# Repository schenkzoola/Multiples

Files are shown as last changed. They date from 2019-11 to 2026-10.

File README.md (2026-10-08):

<picture>
  <source media="(prefers-color-scheme: dark)" srcset="docs/images/logo-light.png">
  Schenktronics
</picture>

# Passive Multiple

A 3HP Eurorack passive multiple from **Schenktronics**. It has two banks of four jacks and a latching pushbutton that links the banks into one 8-jack multiple. It needs no power.

Passive Multiple front panel

## Features

- 3HP Eurorack, 15 mm deep behind the panel (skiff-friendly), and it needs no power
- 2 × 4-jack banks, or 1 × 8 when linked
- A latching link button between the banks: in = linked, out = split
- The whole kit is through-hole, with 30 solder joints

## Documentation

| Document | For | PDF |
|---|-----|-----|
| [User Manual](docs/manual.md) | Using the module | [PDF](docs/pdf/passive-multiple-manual.pdf) |
| [Assembly Guide](docs/assembly-guide.md) | Building the kit | [PDF](docs/pdf/passive-multiple-assembly-guide.pdf) |
| [Bill of Materials](docs/BOM.md) ([CSV](docs/BOM.csv)) | Parts and sourcing | |

## Repository layout

```
hardware/
  multiple/                   Main PCB (KiCad 5.1 schematic, KiCad 10 PCB)
    Multiple.sch                 Schematic
    Multiple.kicad_pcb           PCB layout
    Multiple.step                3D model
    BOM.ods                      Original BOM spreadsheet
  panel/                      Faceplate (KiCad 10, made as an aluminium PCB)
    MultipleFaceplate.kicad_pcb  Faceplate layout
docs/                         Manual, assembly guide, BOM, images
  drawings/                     Scripts that generate the drawings
  pdf/                          PDF versions and their build settings
```

## Fabrication

| Board | Size | Layers | Thickness | Notes |
|---|---|---|---|---|
| Main PCB | 15 × 100 mm | 2 | 1.6 mm | Standard green is fine |
| Faceplate | 15 × 128.5 mm | 1 | 1.6 mm | Aluminium PCB, white solder mask, black silkscreen. Only the front copper layer is used, so FR4 works too. |

## License

This hardware design and its documentation are licensed under [CC BY-NC-SA 4.0](https://creativecommons.org/licenses/by-nc-sa/4.0/). See [LICENSE](LICENSE).

The Schenktronics name and logo are trademarks of Nathan Schenk and are not covered by the CC BY-NC-SA 4.0 license.

## Links

- Tindie: <https://www.tindie.com/products/schenktronics/passive-multiple/>
- ModularGrid: <https://modulargrid.net/e/schenktronics-multiple>
- Build video: <https://www.youtube.com/watch?v=nGc3uMlrRig>
- Website: <https://schenktronics.com>

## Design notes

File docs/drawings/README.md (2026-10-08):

# Drawings

The drawings in the docs are generated by three scripts in this repo, plus one that lives elsewhere (see "Outline drawings" below). The three here use only the Python standard library.

| Script | Makes | From |
|---|---|---|
| [`make_panel_svg.py`](make_panel_svg.py) | `panel.svg`, used in the manual, and `panel-plain.svg`, the panel without captions, used on packaging labels | The faceplate KiCad file |
| [`make_assembly_svgs.py`](make_assembly_svgs.py) | `assembly-*.svg`, used in the assembly guide | The main PCB KiCad file |
| [`make_patch_svgs.py`](make_patch_svgs.py) | `patch-*.svg`, the patch examples in the manual | The faceplate KiCad file |

## Panel drawing

The panel drawing in the [user manual](../manual.md) ([`../images/panel.svg`](../images/panel.svg)) is generated from the KiCad faceplate file, [`MultipleFaceplate.kicad_pcb`](../../hardware/panel/MultipleFaceplate.kicad_pcb).

After changing the faceplate in KiCad, run this from anywhere in the repo:

```sh
python3 docs/drawings/make_panel_svg.py
```

### What it reads

| From the KiCad file | Used for |
|---|---|
| `Edge.Cuts` lines | Panel outline |
| Mounting-hole footprints and their drill sizes | Jacks (Ø6.0), the link button (Ø6.5) and the rack screw holes |
| `F.SilkS` lines, circles and text | Printed lines, the switch symbol and the labels |
| The `SchentronicsLogo` footprint | The logo, read as its silkscreen polygons and placed at the footprint's position and rotation |

The script tells holes apart by drill size, so if you change a hole size, update `JACK` and `SWITCH` at the top of the script. The "Bank A", "Bank B" and "Link button" labels are added by the script, not read from KiCad.

The faceplate file is KiCad 10's S-expression format, read with a small generic S-expression parser in the script (not regexes), since the logo's artwork lives inside a footprint and needs that footprint's position and rotation applied to come out right.

## Assembly drawings

After changing the main PCB in KiCad, run:

```sh
python3 docs/drawings/make_assembly_svgs.py
```

| Drawing | How it's made |
|---|---|
| `assembly-1-switch.svg` | Front and back board views, drawn from the board outline, pads and front silkscreen in the PCB file |
| `assembly-2-cap.svg` | Hand-built side diagram, not from KiCad |
| `assembly-3-faceplate.svg` | Side diagram. The part positions along the board come from the PCB file, and the heights are approximate. |
| `assembly-4-jacks.svg` | Back board view, drawn from the PCB file |

The side views assume the faceplate sits 27 mm further along than the PCB, matching the two KiCad files. If you move the jacks on either board, update `offset` in `fig_faceplate`.

## Patch examples

The patch drawings reuse the panel drawing and add module boxes and cables. Each example is a short function in the script, for example:

```python
def pitch(data):
    p = Patch(data)
    p.source("A1", "Sequencer", "pitch CV out")
    p.dest("A2", "VCO 1", "V/oct in")
    ...
```

Jacks are named by bank and position from the top: `A1`–`A4` and `B1`–`B4`. Sources go on the left, destinations on the right. Pass `color=BLUE` to draw a second signal. To add an example, write a new function, add it to the list in `main()`, and run:

```sh
python3 docs/drawings/make_patch_svgs.py
```

## Outline drawings

`outline-front.svg`, `outline-side.svg`, one `outline-iso-{top,bottom}-{left,right}.svg` per corner, and `outline-bare-parts.svg` (the panel and bare PCB side by side, for the assembly guide's "before you start" shot) are real projections straight from [`ST01_Multiple.step`](../../hardware/ST01_Multiple.step) in `hardware/` — not diagrams. They replace the old product photos in the README, manual and assembly guide. All four isometric corners are generated every run so there's always a fresh set to pick a hero shot from; `outline-iso-top-left.svg` is the one currently used.

**The generator for these doesn't live in this repo.** Unlike the three scripts above, it needs no product-specific logic — point it at any product's STEP files and it works unchanged — so it's kept as one shared tool in the private `schenktronics-business` repo (`claude/skills/schenktronics-product-docs/assets/drawings/make_outline_svg.py`) rather than forked into every product. Regenerate from this repo's root:

```sh
pip install cadquery  # no FreeCAD or other CAD tooling needed
python3 ~/Products/schenktronics-business/claude/skills/schenktronics-product-docs/assets/drawings/make_outline_svg.py \
  --assembly hardware/ST01_Multiple.step \
  --panel hardware/panel/MultipleFaceplate.step \
  --board hardware/multiple/Multiple.step \
  --out docs/images \
  --product "Passive Multiple"
```

(or add a view name at the end, e.g. `... outline-front.svg`, to regenerate just that one)

**This is slow, and not predictably so, especially the front view — read the module docstring in that script before touching it.** Short version: a straight-on view down an axis where many cylindrical parts line up end-on (every jack here, viewed from the front) is a degenerate case for exact-BRep HLR, both slow (the orthographic version of this view took **24 minutes**, against about a **minute each** for the side and isometric views of the same assembly) and prone to rendering a different jack inconsistently on every attempt. The fix that worked — a perspective projection with its apex centered on the model, not tilting the orthographic direction — is explained in full in the script itself, along with everything else worth knowing before changing a view (the explicit HLR axis, scientific-notation coordinate parsing, per-view subprocess isolation, the simplify/crop pass). That script is the one copy serving every product, so fixes and lessons belong there, not duplicated into each product repo's own docs.

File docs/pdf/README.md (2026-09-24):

# PDFs

Printable versions of the docs:

- [User Manual (PDF)](passive-multiple-manual.pdf)
- [Assembly Guide (PDF)](passive-multiple-assembly-guide.pdf)

These are built from [`../manual.md`](../manual.md) and [`../assembly-guide.md`](../assembly-guide.md). **Don't edit the PDFs by hand.** Edit the Markdown instead.

The build tool lives in [schenktronics-docs-tools](https://github.com/schenkzoola/schenktronics-docs-tools), so this repo only holds its settings, in [`config.json`](config.json): the product name, PCB version and which documents to build.

## Automatic builds

The [Build PDFs workflow](../../.github/workflows/pdf.yml) rebuilds the PDFs whenever the docs, their images or `config.json` change on `master`, and commits the new PDFs back. After you push a docs change, wait a minute and then `git pull` to get the rebuilt PDFs.

After an update to schenktronics-docs-tools, run the workflow by hand from the repo's **Actions** tab to rebuild with the new version.

## Previewing locally

See [Previewing locally](https://github.com/schenkzoola/schenktronics-docs-tools#previewing-locally) in the tools repo. In short:

```sh
node ~/Products/schenktronics-docs-tools/pdf/build.mjs docs/pdf/config.json
```

Don't commit the PDFs this produces. Let the workflow build the committed copies.

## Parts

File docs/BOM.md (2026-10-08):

# Bill of Materials — Passive Multiple v1.0

A machine-readable copy is in [BOM.csv](BOM.csv). The original spreadsheet is [hardware/multiple/BOM.ods](../hardware/multiple/BOM.ods).

| Qty | Reference | Part | Manufacturer / Part No. | Notes |
|----:|---|---|---|---|
| 8 | J1–J8 | 3.5 mm mono switched jack, vertical PCB mount, with nut | QingPu WQP-PJ398SM or WQP518MA, or equivalent. Either one works. | [Datasheet / product page](http://www.qingpu-electronics.com/en/products/WQP-PJ398SM-362.html). The switched (normalling) lug is not used. |
| 1 | SW1 | Pushbutton switch, DPDT, latching (push on, push off), PCB mount. It fits either way round. | APEM MHPS2285, or equivalent | [Digi-Key 679-4053-ND](https://www.digikey.com/product-detail/en/apem-inc/MHPS2285/679-4053-ND/1795385). Rated 0.1 A at 30 VDC. An equivalent must be a latching DPDT switch with the same 2 × 3 pin layout, and a plunger that fits the button cap. |
| 1 | — | Button cap, cylindrical, red | Tayda A-5390 (red, 6 × 5 mm) | [Tayda listing](https://www.taydaelectronics.com/push-button-switch-caps-red-color-6-x-5-mm-5390.html). Any cap that fits the MHPS2285 plunger and passes through the 6.5 mm panel hole will work. |
| 1 | — | Main PCB, 15 × 100 mm, 2-layer, 1.6 mm FR4 | Schenktronics | — |
| 1 | — | Faceplate, 3HP (15 × 128.5 mm), 1.6 mm aluminium PCB | Schenktronics | Single-sided, so it can also be made in FR4. |

## Not included

| Qty | Part | Notes |
|----:|---|---|
| 2 | M3 rack screws | Supplied with most Eurorack cases. |

No power cable is needed. The module is passive.

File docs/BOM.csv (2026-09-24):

Qty | Reference | Description | Manufacturer | Part Number | Link
8 | J1-J8 | 3.5mm mono switched jack, vertical, with nut | QingPu | WQP-PJ398SM or WQP518MA | http://www.qingpu-electronics.com/en/products/WQP-PJ398SM-362.html
1 | SW1 | Pushbutton switch, DPDT, latching (or equivalent with same pinout and plunger) | APEM | MHPS2285 | https://www.digikey.com/product-detail/en/apem-inc/MHPS2285/679-4053-ND/1795385
1 |  | Button cap, cylindrical, red, 6x5mm, fits MHPS2285 plunger | Tayda | A-5390 | https://www.taydaelectronics.com/push-button-switch-caps-red-color-6-x-5-mm-5390.html
1 |  | Main PCB, 15x100mm, 2-layer, 1.6mm | Schenktronics | Passive Multiple v1.0
1 |  | Faceplate, 3HP, 1.6mm aluminium PCB | Schenktronics | Passive Multiple Faceplate

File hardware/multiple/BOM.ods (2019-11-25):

Qty | Part No | Manufacturer | Description | Link
8 | WQP-WQP518MA | QuingPu | 3.5mm Jack with nut | http://www.qingpu-electronics.com/en/products/WQP-PJ398SM-362.html
1 | MHPS2285 | APEM | Switch Push DPDT | https://www.digikey.com/product-detail/en/apem-inc/MHPS2285/679-4053-ND/1795385
1 |  |  | Button Cap | https://www.aliexpress.com/item/32375524187.html
1 | PCB | Schenktronics
1 | Faceplate | Schenktronics

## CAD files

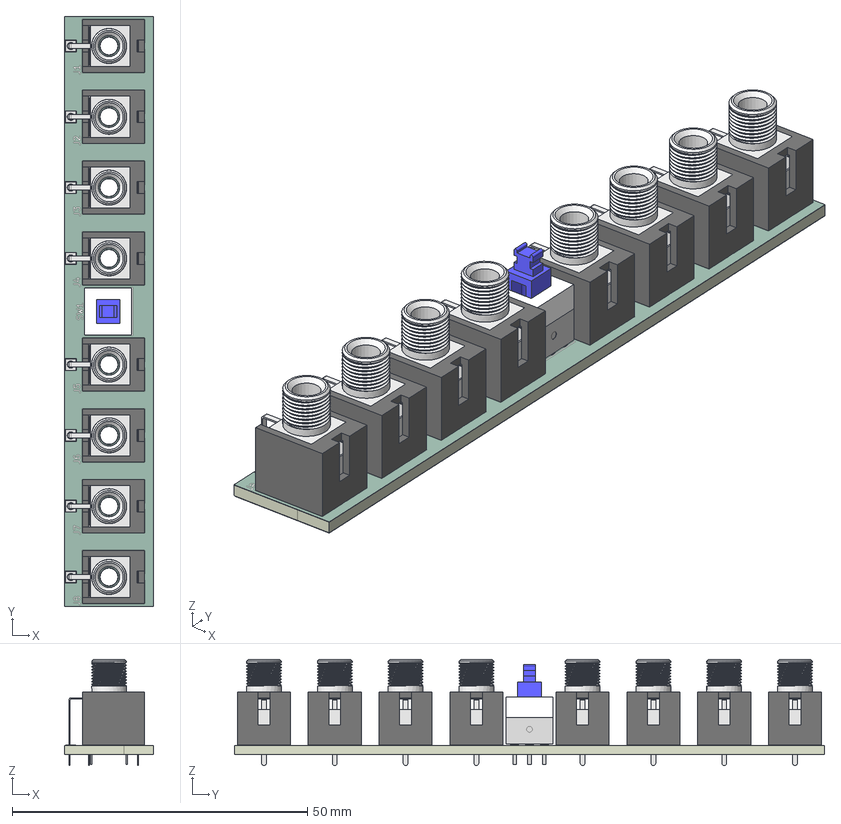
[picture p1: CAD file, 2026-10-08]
hardware/multiple/Multiple.step
15.0 x 100.0 x 18.0 mm
Thonkiconn - PJ398SM v10 x 8
TERMINALS
HOUSEING
actuator
SPRING
Multiple_copper
Multiple_pad
Multiple_silkscreen x 2
Multiple_soldermask x 2
Multiple_PCB

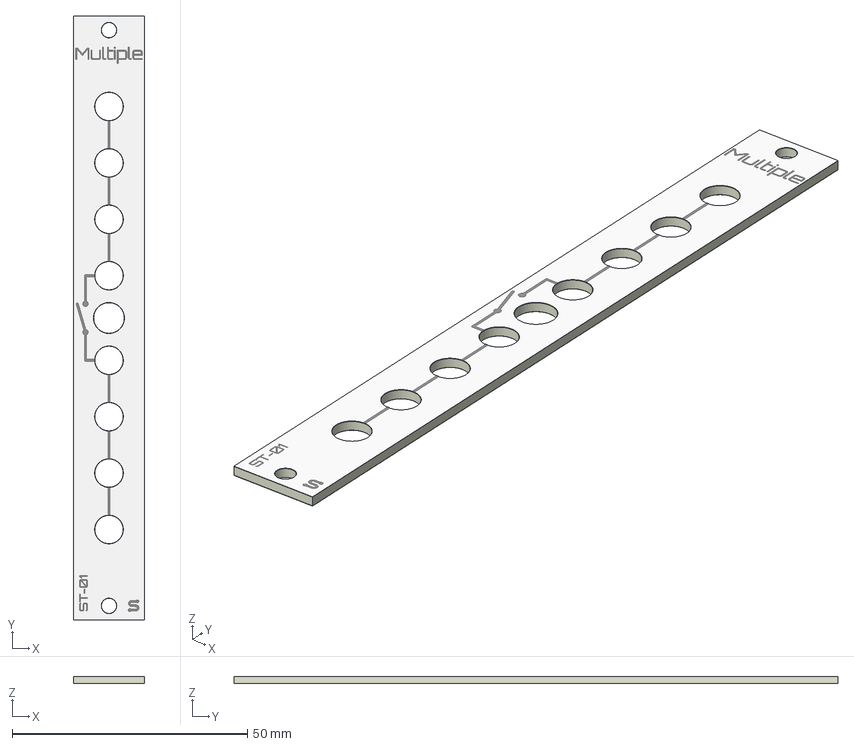
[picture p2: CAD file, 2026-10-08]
hardware/panel/MultipleFaceplate.step
15.0 x 128.5 x 1.64 mm
MultipleFaceplate-unsaved-export-87vEoI_copper
MultipleFaceplate-unsaved-export-87vEoI_silkscreen
MultipleFaceplate-unsaved-export-87vEoI_soldermask x 2
MultipleFaceplate-unsaved-export-87vEoI_PCB

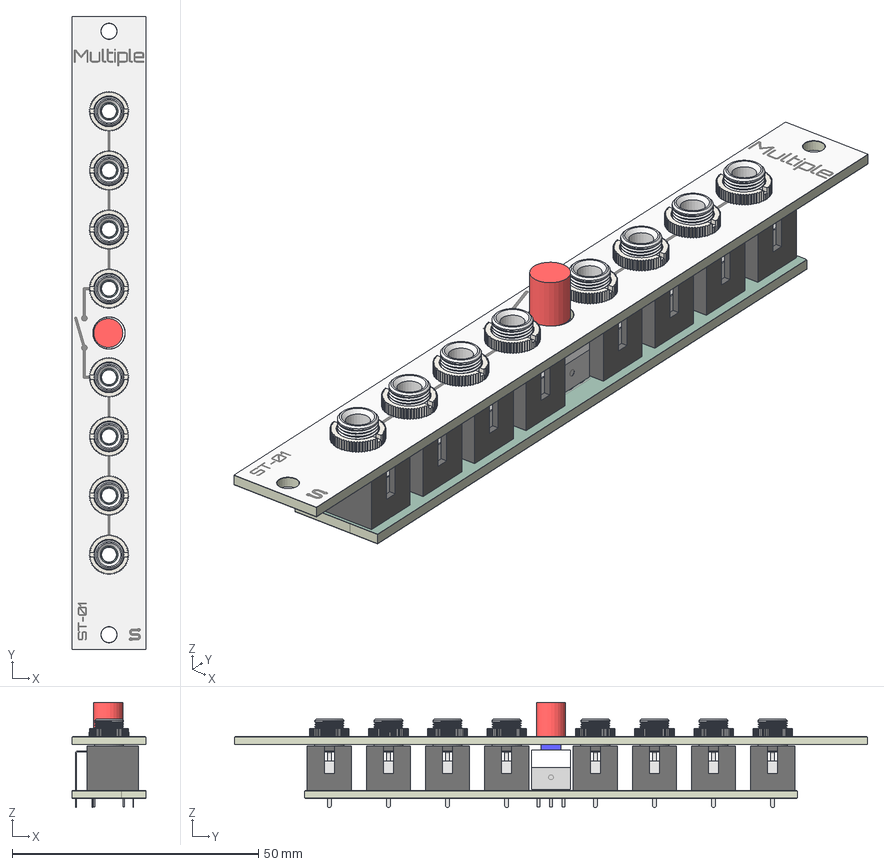
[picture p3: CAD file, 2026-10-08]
hardware/ST01_Multiple.step
15.0 x 128.5 x 21.3 mm
Thonkiconn - PJ398SM v10 x 8
TERMINALS
HOUSEING
actuator
SPRING
Multiple_copper
Multiple_pad
Multiple_silkscreen
Multiple_silkscreen_1
Multiple_soldermask
Multiple_soldermask_1
Multiple_PCB
MultipleFaceplate-unsaved-export-87vEoI_copper
MultipleFaceplate-unsaved-export-87vEoI_silkscreen
MultipleFaceplate-unsaved-export-87vEoI_soldermask
MultipleFaceplate-unsaved-export-87vEoI_soldermask_1
MultipleFaceplate-unsaved-export-87vEoI_PCB
SwitchButton

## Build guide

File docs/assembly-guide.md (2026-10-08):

# Passive Multiple — Assembly Guide

Building this kit takes about 20–30 minutes and needs 30 solder joints. It is a good first Eurorack kit.

**Prefer to watch?** There's a video of the whole build: [Watch me assemble a switched passive multiples module!](https://www.youtube.com/watch?v=nGc3uMlrRig)

The faceplate and the bare PCB, before assembly

## What you need

### Kit contents

Check your kit against this list before you start (full details in the [BOM](BOM.md)):

- [ ] 1 × main PCB
- [ ] 1 × faceplate
- [ ] 8 × 3.5 mm jacks with nuts
- [ ] 1 × latching pushbutton switch
- [ ] 1 × button cap

### Tools

- Soldering iron (about 330–360 °C for leaded solder)
- Solder
- Flush cutters
- Multimeter with a continuity (beep) mode
- Nut driver or wrench for the jack nuts (optional, but it avoids scratching the panel)

## Before you start

- The jacks and switch go on the **front** of the PCB, which is the side with the part outlines (J1–J8, SW1). The side printed "Passive Multiple v1.0 / schenktronics.com" is the back, and you solder there.
- You solder the switch first. **Do not solder the jacks until the faceplate is fitted.** The faceplate holds the jacks in line, and fitting it lets you center the button in its panel hole.

## Step 1 — Solder the switch

1. Insert the switch's six pins into the 2 × 3 SW1 footprint from the front of the PCB. It works either way round, because the footprint is wired symmetrically.
2. Hold it flat against the PCB and square to the board, then solder one pin from the back.
3. Check that the switch still sits flat and straight. If it doesn't, reheat that pin and adjust it.
4. Solder the other five pins. Work quickly so you don't overheat the plastic switch body.
5. Trim the leads with flush cutters.

Front of the PCB with the SW1 position highlighted, and the back of the PCB with the six switch pins highlighted

## Step 2 — Fit the button cap

Press the button cap onto the switch plunger. Press the button a few times to check that it latches in and releases.

Side view of the button cap being pressed down onto the switch plunger

## Step 3 — Fit the jacks and faceplate

1. Insert all eight jacks into J1–J8 from the front of the PCB. Make sure each jack sits flat, with all three legs through their pads. Do not solder them yet.
2. Remove the nuts from the jacks.
3. Lower the faceplate over the jacks. The "Multiple" label goes at the top, next to J1, and the button goes through the larger hole between the two banks.
4. Put the nuts back on and tighten them **finger-tight** for now.
5. Shift the PCB until the button is **centered in its panel hole** and presses in and out without rubbing. The jack legs have a little play in their pads, which gives you room to adjust.
6. Tighten the nuts snugly. Do not overtighten them, because that can crack the jack threads or mark the panel. Then check the button again.

Exploded side view: jacks and button on the PCB, the faceplate above them, and the nuts on top

## Step 4 — Solder the jacks

Turn the assembly over and solder from the back of the PCB.

1. On each jack, solder only the square pad. Then check again that the button is centered and moves freely. If it doesn't, reheat those joints and adjust.
2. Solder the remaining two pads on each jack (24 jack joints in total).
3. Trim any long leads with flush cutters.

Back of the PCB: the eight square pads to tack first are filled red, and the other sixteen jack pads are outlined in red

Inspect every joint. Each one should be shiny and cone-shaped, with no bridges between neighboring pads.

## Step 5 — Test

Test with a multimeter in continuity mode. No power is needed. The "tip" contact is the one that touches the tip of a plugged-in cable; testing is easiest with two patch cables plugged in, probing their plugs.

| Test | Expected result |
|---|---|
| Sleeve of any jack ↔ sleeve of every other jack | Beep |
| Tip ↔ tip, within Bank A (top four) | Beep |
| Tip ↔ tip, within Bank B (bottom four) | Beep |
| Tip of Bank A ↔ tip of Bank B, button **in** | Beep (linked) |
| Tip of Bank A ↔ tip of Bank B, button **out** | No beep (split) |
| Tip ↔ sleeve, any jack, either button position | **No beep.** A beep means a short. Check for solder bridges. |

## Step 6 — Install

Install the module in your case with two M3 screws. Usage details are in the [User Manual](manual.md).

Assembled module, isometric view

## Troubleshooting

| Symptom | Likely cause |
|---|---|
| One jack is dead | That jack has a cold or missing solder joint. Reflow its tip and sleeve legs. |
| The banks never link, or never split, when the button is pressed | There is a bad joint on the switch, or the switch is not fully seated. Reflow the six switch pins. |
| The signal is shorted to ground | There is a solder bridge between a tip pad and a sleeve pad. |
| The button rubs or sticks | The button is not centered in its panel hole. Loosen the nuts, reheat the jack joints, and shift the PCB until it is centered. |

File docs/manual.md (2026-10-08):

# Passive Multiple — User Manual

Passive Multiple front panel

## Overview

The Passive Multiple is a 3HP Eurorack utility module with eight jacks in two banks of four. All jacks in a bank are wired together, so one signal in a bank goes out of the other three jacks. The red button links the two banks, making one 8-jack multiple.

The module has no electronics beyond the jacks and the switch, so it does not need power.

## Specifications

| | |
|---|---|
| Format | Eurorack, 3HP |
| Panel | 15 × 128.5 mm |
| Depth | 15 mm behind the panel (skiff-friendly) |
| Power | None needed |
| Jacks | 8 × 3.5 mm mono (TS) |
| Switch | Latching push-on/push-off button (in = linked), rated 0.1 A / 30 VDC |

Side view of the assembled module, showing the panel, PCB, jacks and switch

## Panel layout

Panel layout: Bank A on top, the link button in the middle, Bank B below

The lines printed on the panel show the connections: jacks joined by a line are wired together, and the switch symbol between the banks is the link button.

## Using the module

### Split mode (button out)

You get two separate 1-in, 3-out multiples. Patch one source into any jack in a bank and take copies from the other three jacks.

### Linked mode (button in)

All eight jacks are wired together, giving you 1 in and 7 out.

### Link button

The button is latching (push on, push off). When it is **in**, the banks are linked. When it is **out**, they are split.

### Using the button as a performance switch

The link button can also be played live. Patch a signal into Bank A and take it out of Bank B. The button then turns that signal on and off. Press it in time with the music to drop a part in and out, mute a modulation source, or cut a clock or gate stream.

You can do this while still using both banks as multiples. Any other jacks in Bank A always carry the signal. The jacks in Bank B only carry it while the button is in.

When the button is out, the Bank B jacks aren't connected to anything, so the modules patched from them get no signal. With audio, you may hear a small click when you switch. The switch changes sharply, so it works best on rhythmic material.

### Signals in any direction

The jacks have no set inputs or outputs, so any jack works as either. You can also use a bank backwards: connect several inputs to one output, or connect one cable to a cable that is too short.

## Patch examples

Each drawing shows the module that sends the signal on the left and the modules that receive it on the right. Any jack in a bank works; the drawings just use the first free ones.

### One clock to four modules

A clock patched into Bank A, with kick and snare taken from Bank A and hi-hat and sequencer taken from Bank B, button in

Patch a clock into Bank A and press the button in. All seven other jacks now carry the clock, so up to seven drum voices, sequencers or clock dividers stay in time. If you only need three copies, leave the button out and use Bank A alone.

### Pitch to three oscillators

A sequencer pitch CV patched into Bank A and sent to three VCOs, button out

Send one sequencer's pitch CV to three VCOs and they play the same notes. Detune them slightly for a thick unison sound, or set them to different octaves. Leave the button out so Bank B stays free for something else. A passive multiple can pull pitch CV slightly out of tune (see [Good practice](#good-practice)), so check the tuning once everything is patched.

### Performance mute

A drum voice patched into Bank A and taken out of Bank B to a mixer; the button turns the signal on and off

Patch a signal into Bank A and take it out of Bank B, as described in [Using the button as a performance switch](#using-the-button-as-a-performance-switch). Press the button in time with the music to drop the part in and out of the mix. This works well for drums, gates and modulation.

### Two separate multiples

With the button out, a clock in Bank A goes to two drums, and an LFO in Bank B goes to a filter and a VCA

With the button out, the module is two separate 1-in, 3-out multiples. Here Bank A spreads a clock to two drum voices, and Bank B sends one LFO to both a filter's cutoff and a VCA, so they move together. Don't press the button in this patch: it would connect the clock and the LFO outputs together.

## Good practice

- **Use one output per bank.** Connecting two module outputs to the same bank (or to linked banks) shorts them together. Most Eurorack outputs have protection resistors and survive this, but the signal you get is meaningless. It is also the most common patching mistake with a multiple.
- **Pitch CV (V/oct):** A passive multiple has no buffering. Most inputs have high impedance, so the load is small, but spreading one pitch CV across many oscillators can drop the voltage slightly and put them a little out of tune. If tuning matters, use a buffered multiple or check the tuning after patching.
- **Audio and gates** work fine through a passive multiple.
- **Grounds:** the sleeves of all eight jacks are wired together, in both modes.

## Installation

1. Power off your case. The module does not need power, but you should never work in a powered case.
2. Place the module in any 3HP space. There is no ribbon cable to connect.
3. Secure it with two M3 rack screws. Do not overtighten them.

## Circuit

Each jack's tip is wired to the other tips in its bank, and all sleeves are wired together. The two poles of the switch are wired in parallel between the Bank A tips and the Bank B tips. The schematic is in [hardware/multiple/Multiple.sch](../hardware/multiple/Multiple.sch) (KiCad 5).

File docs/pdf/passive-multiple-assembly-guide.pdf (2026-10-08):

Building this kit takes about 20–30 minutes and needs 30 solder joints. It is a good first Eurorack kit.

Prefer to watch? There's a video of the whole build: Watch me assemble a switched passive multiples

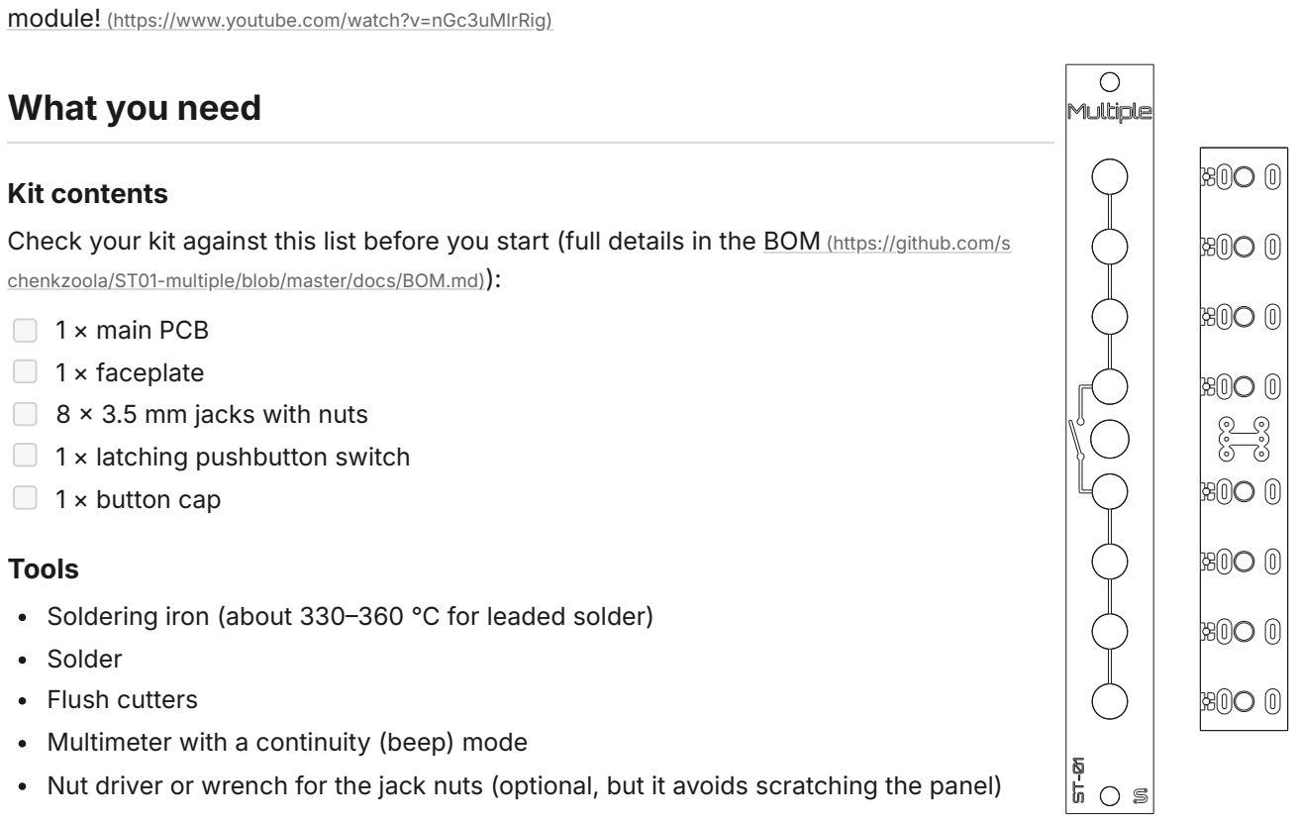
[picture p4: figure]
module! (https://www.youtube.com/watch?v=nGc3uMlrRig); What you need; Kit contents; chenkzoola/ST01-multiple/blob/master/docs/BOM.md)):; 1 × main PCB 1 × faceplate 8 × 3.5 mm jacks with nuts 1 × latching pushbutton switch 1 × button cap; Tools; Solder Flush cutters

Check your kit against this list before you start (full details in the BOM (https://github.com/s

Soldering iron (about 330–360 °C for leaded solder)

Multimeter with a continuity (beep) mode
Nut driver or wrench for the jack nuts (optional, but it avoids scratching the panel)

## Before you start

The jacks and switch go on the front of the PCB, which is the side with the part outlines (J1–J8, SW1). The side printed "Passive Multiple v1.0 / schenktronics.com" is the back, and you solder there.
You solder the switch first. Do not solder the jacks until the faceplate is fitted. The faceplate holds the jacks in line, and fitting it lets you center the button in its panel hole.

## Step 1 — Solder the switch

1. Insert the switch's six pins into the 2 × 3 SW1 footprint from the front of the PCB. It works either way round, because the footprint is wired symmetrically.

# Passive Multiple

## Assembly Guide

For PCB v1.0 · Updated 2026-10-08
Official version: github.com/schenkzoola/ST01-multiple
Passive Multiple · Assembly Guide · PCB v1.0 | schenktronics.com · CC BY-NC-SA 4.0 | Page 1 of 4

2. Hold it flat against the PCB and square to the board, then solder one pin from the back.
3. Check that the switch still sits flat and straight. If it doesn't, reheat that pin and adjust it.
4. Solder the other five pins. Work quickly so you don't overheat the plastic switch body.
5. Trim the leads with flush cutters.

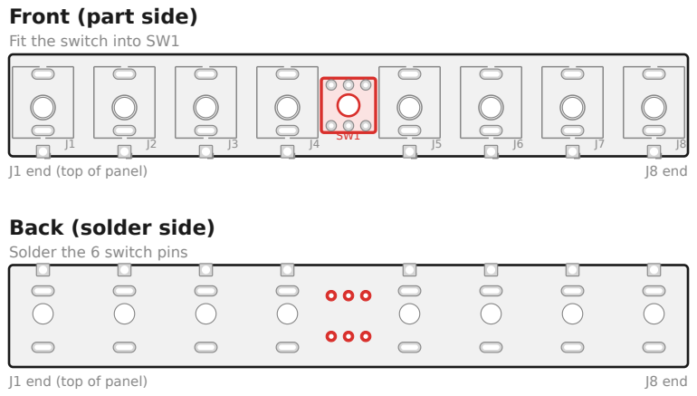
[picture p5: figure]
Front (part side); Fit the switch into SW1; J1 end (top of panel); J8 end; Back (solder side); Solder the 6 switch pins

## Step 2 — Fit the button cap

Press the button cap onto the switch plunger. Press the button a few times to check that it latches in and

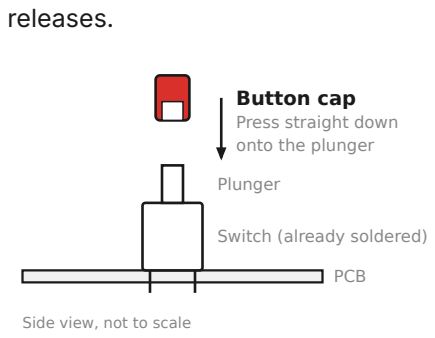
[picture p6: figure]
releases.; PCB; Button cap Press straight down onto the plunger; Plunger; Switch (already soldered); Side view, not to scale

## Step 3 — Fit the jacks and faceplate

1. Insert all eight jacks into J1–J8 from the front of the PCB. Make sure each jack sits flat, with all three legs through their pads. Do not solder them yet.
2. Remove the nuts from the jacks.
3. Lower the faceplate over the jacks. The "Multiple" label goes at the top, next to J1, and the button goes through the larger hole between the two banks.
4. Put the nuts back on and tighten them finger-tight for now.
5. Shift the PCB until the button is centered in its panel hole and presses in and out without rubbing. The jack legs have a little play in their pads, which gives you room to adjust.
6. Tighten the nuts snugly. Do not overtighten them, because that can crack the jack threads or mark the panel. Then check the button again.
Passive Multiple · Assembly Guide · PCB v1.0 | schenktronics.com · CC BY-NC-SA 4.0 | Page 2 of 4

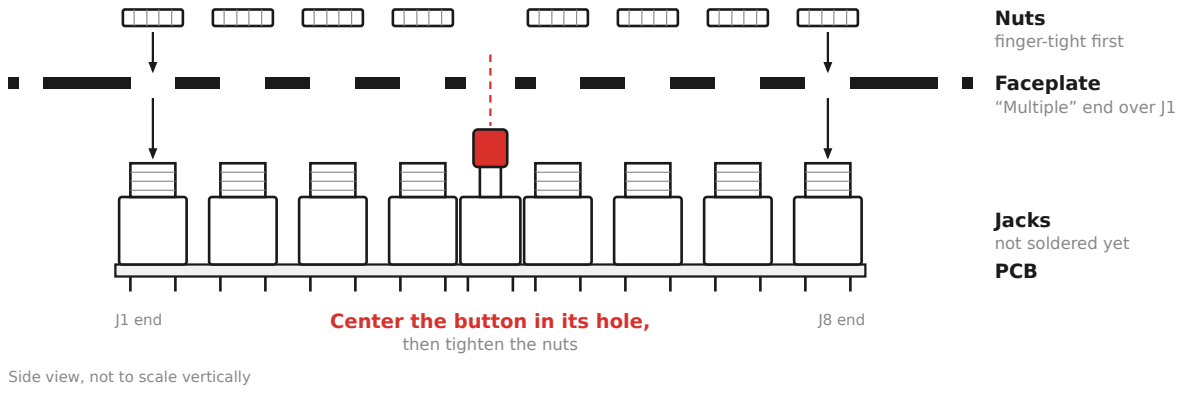
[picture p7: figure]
Nuts finger-tight first; Faceplate “Multiple” end over J1; Jacks not soldered yet PCB; Center the button in its hole, then tighten the nuts; J1 end; J8 end; Side view, not to scale vertically

## Step 4 — Solder the jacks

Turn the assembly over and solder from the back of the PCB.
1. On each jack, solder only the square pad. Then check again that the button is centered and moves freely. If it doesn't, reheat those joints and adjust.
2. Solder the remaining two pads on each jack (24 jack joints in total).
3. Trim any long leads with flush cutters.

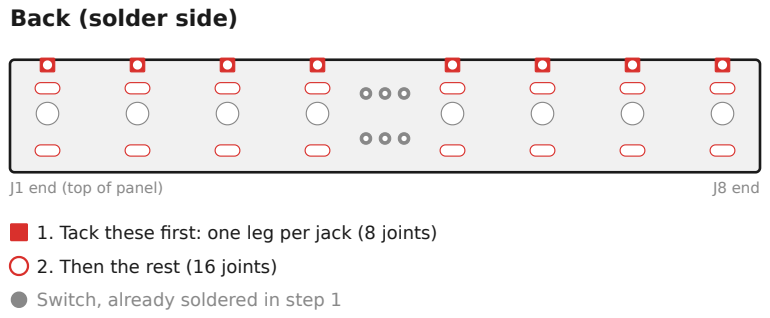
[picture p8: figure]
Back (solder side); J1 end (top of panel); J8 end; 2. Then the rest (16 joints); Switch, already soldered in step 1

1. Tack these first: one leg per jack (8 joints)

Inspect every joint. Each one should be shiny and cone-shaped, with no bridges between neighboring pads.

## Step 5 — Test

Test with a multimeter in continuity mode. No power is needed. The "tip" contact is the one that touches the tip of a plugged-in cable; testing is easiest with two patch cables plugged in, probing their plugs.

Test | Expected result

Sleeve of any jack ↔ sleeve of every other jack Beep

Tip ↔ tip, within Bank A (top four) | Beep
Tip ↔ tip, within Bank B (bottom four) | Beep
Tip of Bank A ↔ tip of Bank B, button in | Beep (linked)
Tip of Bank A ↔ tip of Bank B, button out | No beep (split)
Tip ↔ sleeve, any jack, either button position | No beep. A beep means a short. Check for solder bridges.
Passive Multiple · Assembly Guide · PCB v1.0 | schenktronics.com · CC BY-NC-SA 4.0 | Page 3 of 4

## Step 6 — Install

Install the module in your case with two M3 screws. Usage details are in the User Manual (https://github.com/schenk
zoola/ST01-multiple/blob/master/docs/manual.md). (https://github.com/schenkzoola/ST01-multiple/blob/master/docs/manual.md)

## Troubleshooting

Symptom | Likely cause
One jack is dead | That jack has a cold or missing solder joint. Reflow its tip and sleeve legs.
The banks never link, or never split, when the button is pressed | There is a bad joint on the switch, or the switch is not fully seated. Reflow the six switch pins.
The signal is shorted to ground | There is a solder bridge between a tip pad and a sleeve pad.
The button rubs or sticks | The button is not centered in its panel hole. Loosen the nuts, reheat the jack joints, and shift the PCB until it is centered.
Passive Multiple · Assembly Guide · PCB v1.0 | schenktronics.com · CC BY-NC-SA 4.0 | Page 4 of 4

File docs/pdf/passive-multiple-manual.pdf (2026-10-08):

## Overview

The Passive Multiple is a 3HP Eurorack utility module with eight jacks in two banks of four. All jacks in a bank are wired together, so one signal in a bank goes out of the other three jacks. The red button links the two banks, making one 8-jack multiple.

The module has no electronics beyond the jacks and the switch, so it does not need power.

## Specifications

Format Eurorack, 3HP

Panel | 15 × 128.5 mm
Depth | 15 mm behind the panel (skiff-friendly)
Power | None needed
Jacks | 8 × 3.5 mm mono (TS)
Switch | Latching push-on/push-off button (in = linked), rated 0.1 A / 30 VDC

# Passive Multiple

## User Manual

For PCB v1.0 · Updated 2026-10-08
Official version: github.com/schenkzoola/ST01-multiple
Passive Multiple · User Manual · PCB v1.0 | schenktronics.com · CC BY-NC-SA 4.0 | Page 1 of 7

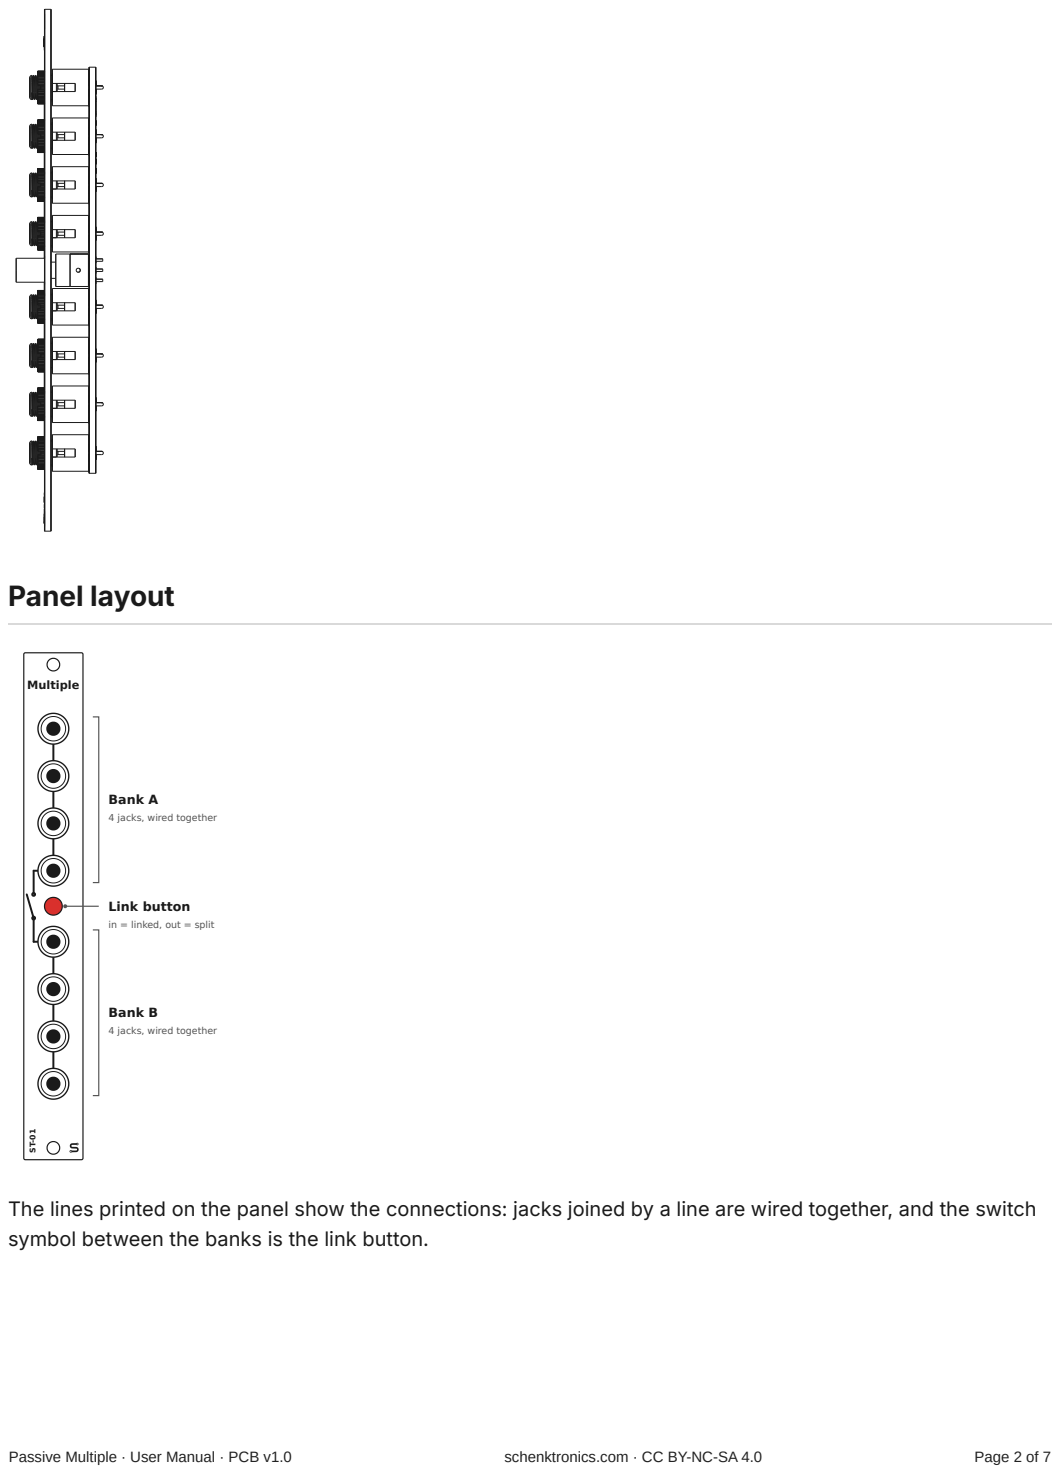
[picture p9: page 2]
Panel layout; Multiple; Passive Multiple · User Manual · PCB v1.0; schenktronics.com · CC BY-NC-SA 4.0; Page 2 of 7

Bank A
4 jacks, wired together

Link button
in = linked, out = split

Bank B

The lines printed on the panel show the connections: jacks joined by a line are wired together, and the switch
symbol between the banks is the link button.

## Using the module

Split mode (button out)
You get two separate 1-in, 3-out multiples. Patch one source into any jack in a bank and take copies from the other three jacks.

Linked mode (button in)
All eight jacks are wired together, giving you 1 in and 7 out.

Link button
The button is latching (push on, push off). When it is in, the banks are linked. When it is out, they are split.

Using the button as a performance switch
The link button can also be played live. Patch a signal into Bank A and take it out of Bank B. The button then turns that signal on and off. Press it in time with the music to drop a part in and out, mute a modulation source, or cut a clock or gate stream.

You can do this while still using both banks as multiples. Any other jacks in Bank A always carry the signal. The jacks in Bank B only carry it while the button is in.

When the button is out, the Bank B jacks aren't connected to anything, so the modules patched from them get no signal. With audio, you may hear a small click when you switch. The switch changes sharply, so it works best on rhythmic material.

Signals in any direction
The jacks have no set inputs or outputs, so any jack works as either. You can also use a bank backwards: connect several inputs to one output, or connect one cable to a cable that is too short.

## Patch examples

Each drawing shows the module that sends the signal on the left and the modules that receive it on the right. Any jack in a bank works; the drawings just use the first free ones.

Passive Multiple · User Manual · PCB v1.0 | schenktronics.com · CC BY-NC-SA 4.0 | Page 3 of 7

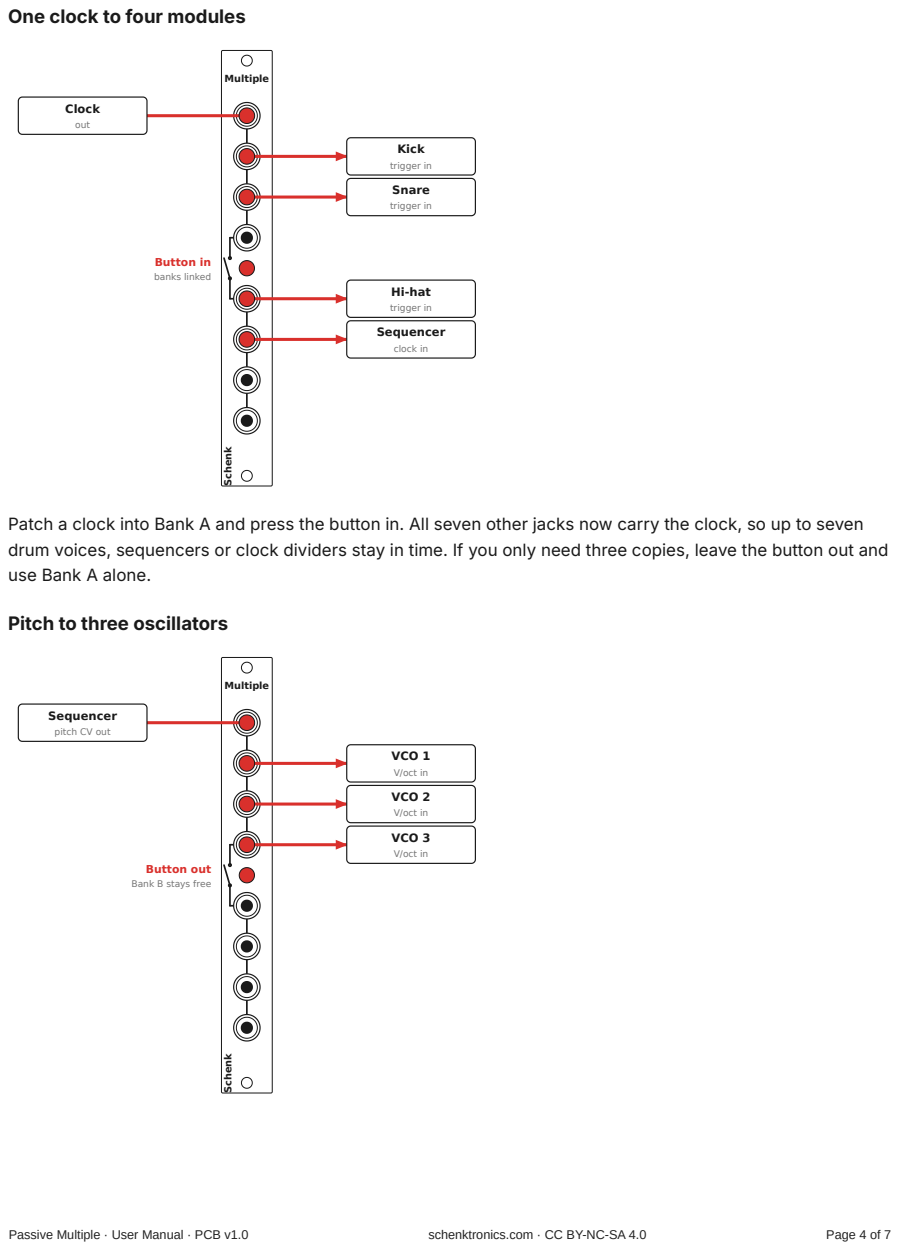
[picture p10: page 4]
Schenk; Multiple; Clock; out; Kick; trigger in; Snare; Hi-hat; Sequencer; clock in; Button in banks linked; VCO 1; V/oct in; VCO 2; VCO 3; Passive Multiple · User Manual · PCB v1.0; schenktronics.com · CC BY-NC-SA 4.0; Page 4 of 7

One clock to four modules

Patch a clock into Bank A and press the button in. All seven other jacks now carry the clock, so up to seven
drum voices, sequencers or clock dividers stay in time. If you only need three copies, leave the button out and
use Bank A alone.

Pitch to three oscillators

Sequencer
pitch CV out

Button out
Bank B stays free

Send one sequencer's pitch CV to three VCOs and they play the same notes. Detune them slightly for a thick unison sound, or set them to different octaves. Leave the button out so Bank B stays free for something else. A passive multiple can pull pitch CV slightly out of tune (see Good practice), so check the tuning once

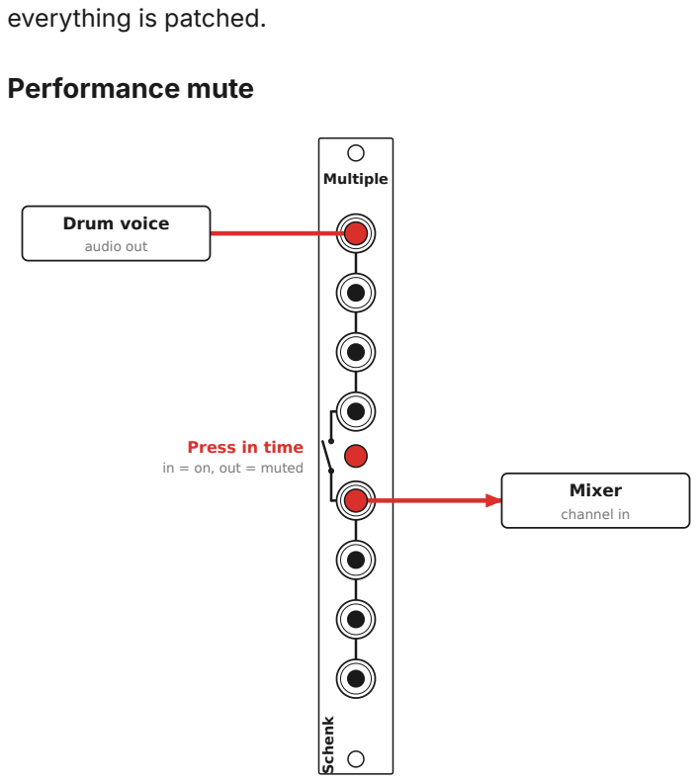
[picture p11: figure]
everything is patched.; Performance mute; Schenk; Multiple; Drum voice; audio out; Mixer; channel in; Press in time in = on, out = muted

Patch a signal into Bank A and take it out of Bank B, as described in Using the button as a performance switch. Press the button in time with the music to drop the part in and out of the mix. This works well for drums, gates and modulation.

Passive Multiple · User Manual · PCB v1.0 | schenktronics.com · CC BY-NC-SA 4.0 | Page 5 of 7

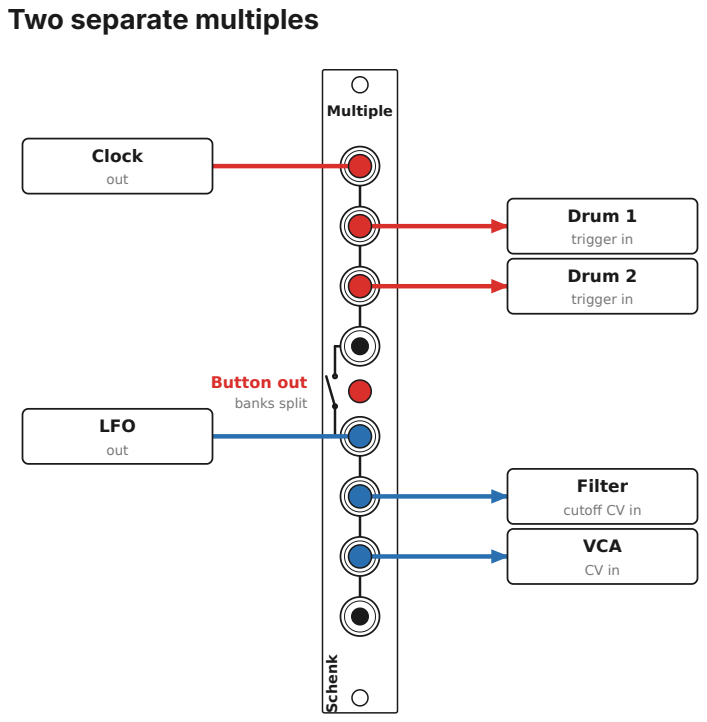
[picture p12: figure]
Two separate multiples; Schenk; Multiple; Clock; out; Drum 1; trigger in; Drum 2; LFO; Filter; cutoff CV in; VCA; Button out banks split

With the button out, the module is two separate 1-in, 3-out multiples. Here Bank A spreads a clock to two drum voices, and Bank B sends one LFO to both a filter's cutoff and a VCA, so they move together. Don't press the button in this patch: it would connect the clock and the LFO outputs together.

## Good practice

Use one output per bank. Connecting two module outputs to the same bank (or to linked banks) shorts them together. Most Eurorack outputs have protection resistors and survive this, but the signal you get is meaningless. It is also the most common patching mistake with a multiple.
Pitch CV (V/oct): A passive multiple has no buffering. Most inputs have high impedance, so the load is small, but spreading one pitch CV across many oscillators can drop the voltage slightly and put them a little out of tune. If tuning matters, use a buffered multiple or check the tuning after patching.
Audio and gates work fine through a passive multiple.
Grounds: the sleeves of all eight jacks are wired together, in both modes.

## Installation

1. Power off your case. The module does not need power, but you should never work in a powered case.
2. Place the module in any 3HP space. There is no ribbon cable to connect.
3. Secure it with two M3 rack screws. Do not overtighten them.
Passive Multiple · User Manual · PCB v1.0 | schenktronics.com · CC BY-NC-SA 4.0 | Page 6 of 7

## Circuit

Each jack's tip is wired to the other tips in its bank, and all sleeves are wired together. The two poles of the switch are wired in parallel between the Bank A tips and the Bank B tips. The schematic is in
hardware/multiple/Multiple.sch (https://github.com/schenkzoola/ST01-multiple/blob/master/hardware/multiple/Multiple.sch) (KiCad
5).
Passive Multiple · User Manual · PCB v1.0 | schenktronics.com · CC BY-NC-SA 4.0 | Page 7 of 7

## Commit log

2019-11-25 Add top layer gnd pour
    [PassiveMultiples.kicad_pcb]
2019-11-25 Add BOM
    [BOM.ods]
2019-11-26 Update switch footprint
    Generate gerbers and step
    [PassiveMultiples-B_Cu.gbr, PassiveMultiples-B_Mask.gbr, PassiveMultiples-B_Paste.gbr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]
2019-11-27 Move jacks to try to center them
    [PassiveMultiples-B_Cu.gbr, PassiveMultiples-B_Mask.gbr, PassiveMultiples-B_Paste.gbr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]
2019-11-27 Add faceplate .dxf
    [PassiveMultiplesFaceplate.dxf]
2019-11-27 Create faceplate PCB
    [PassiveMultiplesFaceplate-B_Cu.gbr, PassiveMultiplesFaceplate-B_Mask.gbr, PassiveMultiplesFaceplate-B_Paste.gbr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]
2019-11-28 add gerbers.zip
2026-09-24 Add product documentation and CC BY-NC-SA 4.0 license
    Add a README, user manual, assembly guide, and BOM (Markdown and CSV),
    with cropped product photos for the docs. License the design and docs
    under CC BY-NC-SA 4.0.
    [BOM.csv]
2026-09-24 Describe using the link button as a performance switch
    Also shorten the rack screw note and simplify the circuit description.
2026-09-24 Add generated panel drawing to the manual
    Replace the ASCII panel diagram with an SVG line drawing generated from
    the KiCad faceplate file by docs/drawings/make_panel_svg.py.
2026-09-24 Add assembly step drawings and build video link
    Generate front/back board views and side diagrams for each assembly
    step from the KiCad PCB file (docs/drawings/make_assembly_svgs.py),
    and link the build video from the assembly guide.
2026-09-24 Add patch examples to the manual
    Four patch examples with drawings generated from the faceplate KiCad
    file by docs/drawings/make_patch_svgs.py.
2026-09-24 Add PDF build pipeline for the manual and assembly guide
    Build styled PDFs from the Markdown docs with marked and headless
    Chrome (docs/pdf/build.mjs), and rebuild them on every docs change with
    a GitHub Action that commits the results. Also crop the panel photos
    tighter and enlarge the patch drawing labels for print.
2026-09-24 Add 15 mm depth to the specs
2026-09-24 Add Tayda button cap to BOM and make PDF builds reproducible
    List Tayda A-5390 as the button cap supplier. Pin the PDF creation and
    modification dates to each document's "Updated" date, so rebuilding
    unchanged docs produces identical files and the Action only commits
    PDFs when their content changes.
    [BOM.csv]
2026-09-24 Stop naming part brands in the kit checklist
    The kit may ship with switches from other vendors, so the assembly
    guide's checklist now says "latching pushbutton switch", and the BOM
    marks its reference parts "or equivalent", listing what a substitute
    must match. Also drop the "Thonkiconn" label from the jacks, since
    they aren't Thonk parts.
    [BOM.csv]
2026-09-24 Add a plain panel drawing for packaging labels
    make_panel_svg.py now also writes panel-plain.svg, the panel without
    its captions. Thermal label printers print pure black and white, and
    the annotated drawing's small grey captions don't survive that.
2026-09-24 Describe the faceplate as an aluminium PCB
    The docs assumed FR4, but the faceplates are made as aluminium PCBs.
    The design only uses the front copper layer, so FR4 still works.
    [BOM.csv]
2026-10-01 Update faceplate to new logo. Regenerate gerbers.
    [PassiveMultiplesFaceplate-B_Cu.gbr, PassiveMultiplesFaceplate-B_Mask.gbr, PassiveMultiplesFaceplate-B_Paste.gbr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]
2026-10-01 Regenerate the panel drawings for the new faceplate
    The faceplate moved to KiCad 10's S-expression format and gained the
    Schentronics logo as a footprint. The old regex-based parser couldn't
    read the new file, so make_panel_svg.py now uses a small generic
    S-expression reader and resolves the logo's polygons through its
    footprint's position and rotation. Verified against a kicad-cli render
    of the faceplate's silkscreen.
2026-10-07 Add ST-01 part number and CC BY-NC-SA mark to the main PCB
    Four CC badges (Attribution, NonCommercial, ShareAlike, and the
    Creative Commons roundel) as real footprint instances from
    _NTSFootprints, not hand-drawn graphics, split across two rows so
    they clear the neighboring jacks. ST-01 and the CC BY-NC-SA 4.0 text
    moved to their own gap. The existing Passive Multiple/schenktronics.com
    text was repositioned, not removed. Verified centered and square
    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
    [PassiveMultiples.kicad_pcb]
2026-10-07 Faceplate: S-mark + ST-01 moved to the hole-centered scheme, Orbitron text
    S-mark moves from lower-left to the gap right of the bottom hole
    (1.09mm margin each side) -- too narrow for the full wordmark, so this
    is the small-mark branch of the new placement rule. ST-01 moves from
    lower-right to the left gap, vertical, justify-left anchored to the
    S-mark's bottom. Header and part number switched from italic KiCad
    stroke font to upright Orbitron.
    Note: this file carries other pending local changes from before this
    edit, not just the faceplate update above.
    [PassiveMultiplesFaceplate.kicad_pcb]
2026-10-07 Title blocks: add logo worksheet link and fill in consistent fields
    Set page_layout_descr_file (pcbnew and schematic) to the real
    Schenktronics worksheet path, so its embedded logo loads. Neither PCB
    had a title block at all; added one each, rev 1.1 to match the real
    "ST-01 v1.1" silkscreen text, company "Schenktronics".
    [PassiveMultiples.kicad_pcb, PassiveMultiplesFaceplate.kicad_pcb]
2026-10-07 Title block: add Dolibarr PCB ref (PCB-ST01-MAIN / PCB-ST01-FACE) as comment 4
    [PassiveMultiples.kicad_pcb, PassiveMultiplesFaceplate.kicad_pcb]
2026-10-07 Main PCB: drop the CC icon roundels, keep the license text
    Nathan's own edit in KiCad: removed the four CC BY-NC-SA icon roundels
    (Attribution/ShareAlike/Noncommercial/base), keeping just the
    "CC BY-NC-SA 4.0" text line -- standardizing this board to match the
    text-only convention the other three ended up on, where the icons
    didn't reliably fit.
    [PassiveMultiples.kicad_pcb]
2026-10-08 Regenerate gerbers: dropped CC roundels, fixed-ring faceplate output
    Main board reflects the CC-roundel removal (text-only license mark
    now). Faceplate picks up the squeezed wordmark, tick marks, and the
    resized/removed jack rings.
    Cleaned up stale duplicate output from an older KiCad version's naming
    (*_SilkS.gbr vs this version's *_Silkscreen.gbr; old .gbr drill maps
    superseded by the PDF ones). Both zips rebuilt to match.
    kicad-cli also filled in a block of default ERC/schematic settings in
    PassiveMultiples.kicad_pro that weren't previously written to the file
    (standard defaults, not a configuration change) -- a side effect of
    loading the project, not something done deliberately.
    [PassiveMultiples-B_Cu.gbr, PassiveMultiples-B_Mask.gbr, PassiveMultiples-B_Paste.gbr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]
2026-10-08 Restructure into hardware/ and manufacturing/, matching Quad Mixer's layout
    PassiveMultiples/ -> hardware/multiple/ (source) and manufacturing/multiple/
    (gerbers, moved out of the project folder). PassiveMultiplesFaceplate/ ->
    hardware/panel/ and manufacturing/panel/ (gerbers plus the panel .dxf).
    KiCad project filenames are unchanged, only their containing folder moved.
    Updates the drawing scripts' hardcoded paths, README's repository-layout
    diagram, and the manual/BOM links -- also fixing BOM.md's faceplate
    gerbers link, which pointed at a filename (...FaceplateGerbers.zip) that
    never actually existed; the real file is PassiveMultiplesFaceplate.zip.
    Regenerated docs/images/panel.svg and p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
    [BOM.ods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]
2026-10-08 Rename the KiCad projects from PassiveMultiples to Multiple
    PassiveMultiples -> Multiple (main PCB), PassiveMultiplesFaceplate ->
    MultipleFaceplate, matching the product's current name and the
    hardware/multiple + hardware/panel folders. Renames every project file
    (.kicad_pcb, .kicad_pro, .pro, .sch, .step, -cache.lib) and fixes the
    internal self-references inside .kicad_pro (filename/netlist/sheet name
    fields) and the legacy .pro's LastNetListRead line.
    Also fixes sym-lib-table, which pointed at an absolute path from before
    either of the last two restructures (~/Products/Multiples/PassiveMultiples/...)
    -- switched to ${KIPRJMOD}-relative, matching Quad Mixer's own
    fp-lib-table convention, s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
    [Multiple-B_Cu.gbr, Multiple-B_Mask.gbr, Multiple-B_Paste.gbr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]
2026-10-08 Fix internal self-references missed in the previous commit's staging
    The .kicad_pro/.pro edits were made after the git mv already staged the
    rename, so the content fix (filename/netlist/name fields) never made it
    into the previous commit -- caught this because the rebase before push
    refused with unstaged changes. Also properly removes the old
    PassiveMultiplesFaceplate.kicad_prl now that it's renamed, rather than
    leaving both tracked.
2026-10-08 Remove stale KiCad legacy/cache/backup files
    - Multiple.pro / MultipleFaceplate.pro: legacy KiCad 4/5 project files,
    superseded by the already-tracked .kicad_pro
    - Multiple.net: legacy netlist export; modern KiCad links schematic
    and PCB directly, no standalone netlist file needed
    - fp-info-cache (both boards): footprint-library scan cache, KiCad
    regenerates this automatically, never meant to be committed
    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
2026-10-08 Generate step files
    [Multiple.kicad_pcb, Multiple.step, MultipleFaceplate.kicad_pcb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]
2026-10-08 Fix jack centering
    [Multiple.kicad_pcb, Multiple.step]
2026-10-08 Add assembly step file
    [ST01_Multiple.step]
2026-10-08 Generate mechanical outline drawings from the assembly STEP file
    Replaces the product photos in the README, manual and assembly guide
    with real HLR projections of the module straight from
    hardware/ST01_Multiple.step: a front view, a side profile, four
    isometric hero-angle candidates, and a bare panel+PCB view for the
    assembly guide's "before you start" shot.
    The front view needed a perspective projection (not orthographic) to
    avoid a degenerate HLR tie-breaking case when looking straight down the
    jacks' coaxial barrels, which otherwise rendered a different jack
    inconsistently on every attempt.
2026-10-08 Remove product photos superseded by generated outline drawings
    front.jpg, assembled.jpg and pcb-and-panel.jpg are no longer referenced
    anywhere now that the README, manual and assembly guide use the STEP-
    generated outline SVGs instead.
2026-10-08 Stop tracking generated manufacturing files
    Gerbers, drill files, drill maps/report and the panel .dxf are
    entirely regenerable from the KiCad PCB files in hardware/, so
    they're gitignored now instead of committed (see the new
    make_manufacturing_files.py in schenktronics-business). The files
    stay on disk locally, just untracked.
    Updated the README's Fabrication section and the BOM's gerber links
    accordingly, since those files no longer exist in the public repo for
    a buyer to download directly.
    [Multiple-B_Cu.gbr, Multiple-B_Mask.gbr, Multiple-B_Paste.gbr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]
2026-10-08 Drop manufacturing-file mentions from public docs entirely
    No pointer to where gerbers come from, no regeneration instructions,
    no contact note — the public repo just doesn't mention that step.
